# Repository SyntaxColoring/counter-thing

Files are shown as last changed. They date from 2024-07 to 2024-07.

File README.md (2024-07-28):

# Introduction

The Counter Thing is a hardware device with a button and numeric display. It currently counts days going up, and resets to 0 when you press the button.

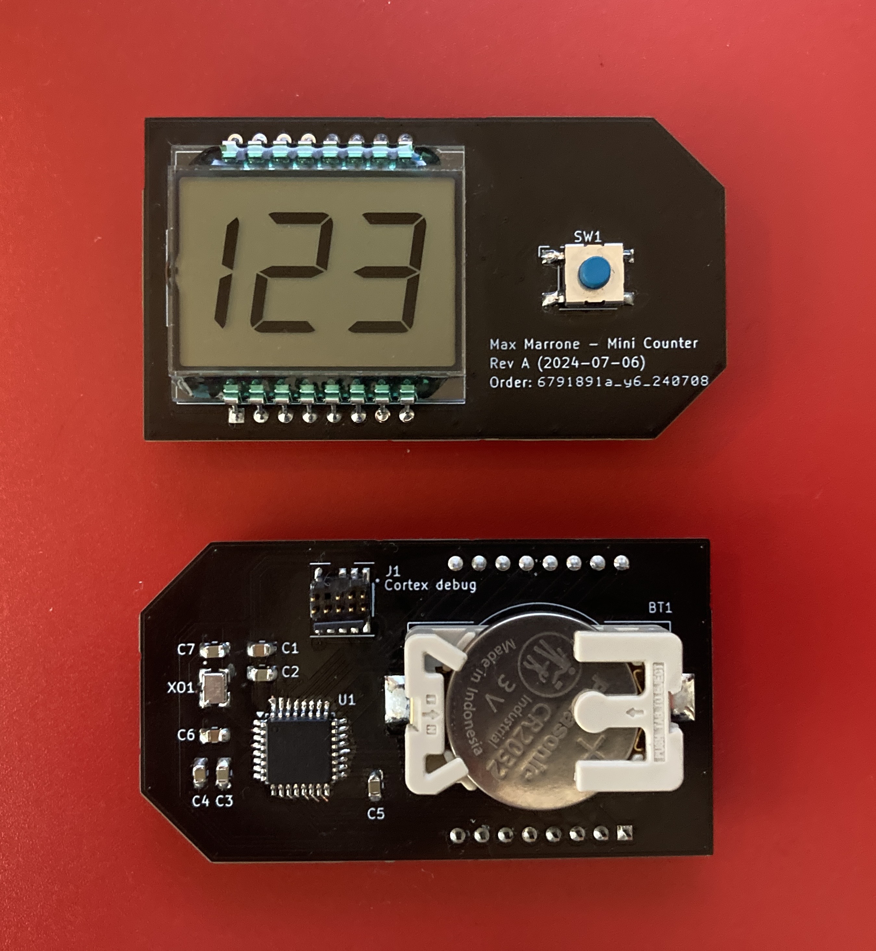
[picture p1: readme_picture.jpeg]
The front and back of the printed circuit board assembly. The front has a numeric display and a button. The back has a CR2032 battery and several smaller components. PCB front and back


I should run ~1 year on a CR2032 battery and keep time with a drift of <15 minutes/year.

I use a few as household reminders, like keeping track of how many days it's been since I've last vacuumed or watered my plants.

This repository holds everything for the project (electronics and software).

# File organization

[pcb/](./pcb/) has the KiCad project files for the latest version of the board. [pcb/fabrication_outputs/](./pcb/fabrication_outputs) has pre-exported Gerbers and such, ready to send to a fab. I used JLCPCB, but any of them will probably work.

[firmware/](./firmware/) has the STM32CubeIDE project files and source code for the firmware.

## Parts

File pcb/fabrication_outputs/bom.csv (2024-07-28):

Designator | Footprint | Quantity | Value | LCSC Part #
BT1 | BA2032SM | 1 | BA2032SM | BA2032SM
C1 | 0805 | 1 | 10u | C0805C106K8PAC7800
C2, C3, C5, C7 | 0805 | 4 | 100n | C0805C104K5RAC7210
C4 | 0805 | 1 | 1u | C0805C105K4RAC7800
C6 | 0805 | 1 | 10n | C0805C103K1RAC7800
DS1 | LCD-A2X1C50TR | 1 | LCD-A2X1C50TR | LCD-A2X1C50TR
J1 | SAMTEC_FTSH-105-X-X-DV-007-P-X | 1 | FTSH-105-01-L-DV-007-K | FTSH-105-01-L-DV-007-K
SW1 | SW_SPST_Omron_B3FS-101xP | 1 | B3FS-1015 | B3FS-1015
U1 | LQFP-32_7x7mm_P0.8mm | 1 | STM32L010K4T6 | STM32L010K4T6
XO1 | OSC_ECS-327KE-TR_HandSolder | 1 | ECS-327KE-TR | ECS-327KE-TR

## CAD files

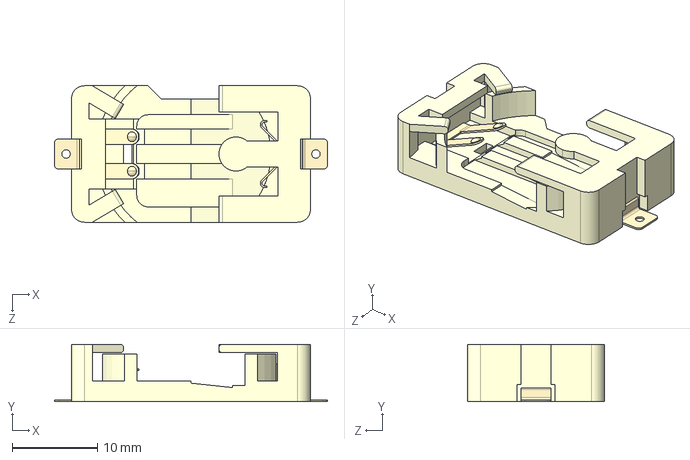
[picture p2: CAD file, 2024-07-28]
pcb/project_libraries/3d/BA2032SM.step
32.0 x 6.70 x 16.0 mm

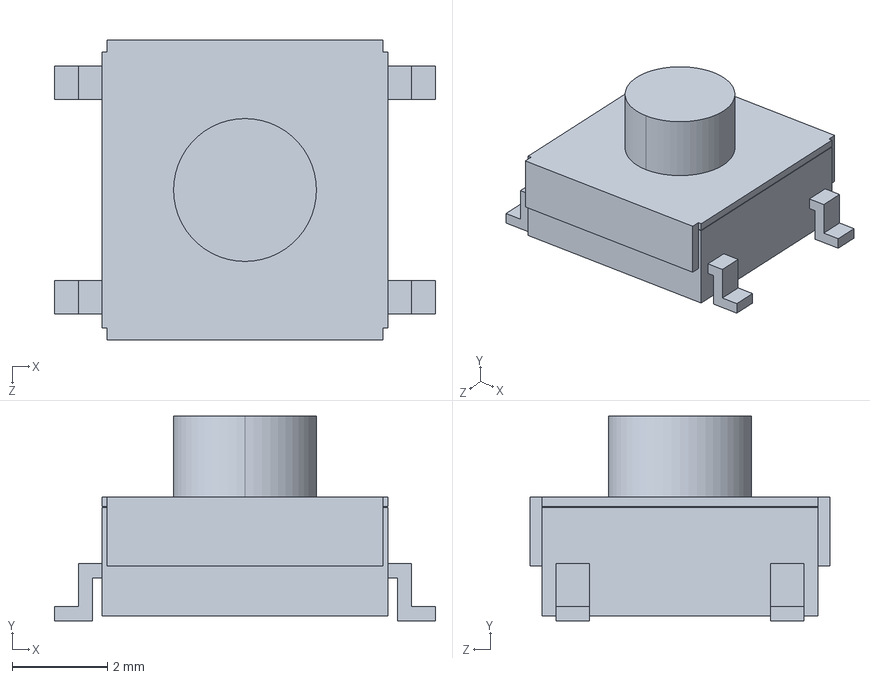
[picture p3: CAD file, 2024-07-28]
pcb/project_libraries/3d/B3FS_101[].step
8.00 x 4.30 x 6.30 mm

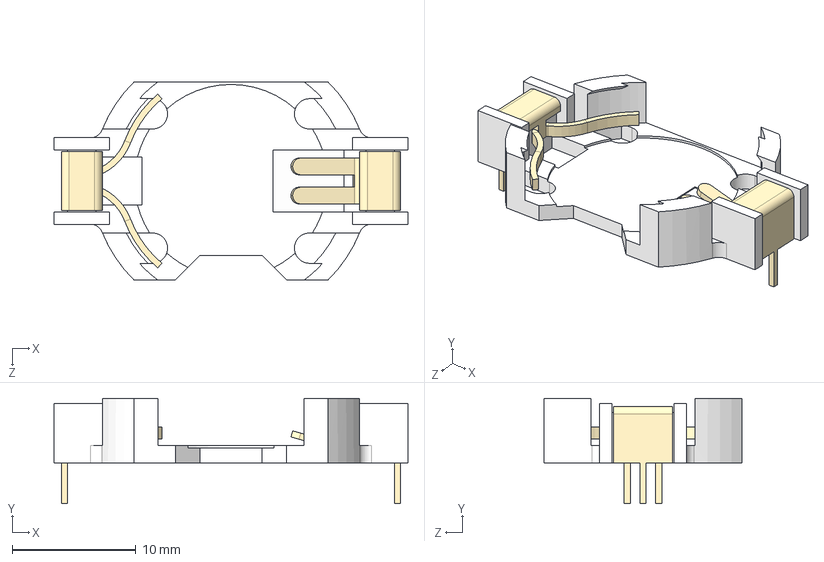
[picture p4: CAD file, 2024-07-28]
pcb/project_libraries/3d/BU2032-1-G.STEP
28.6 x 8.50 x 16.0 mm

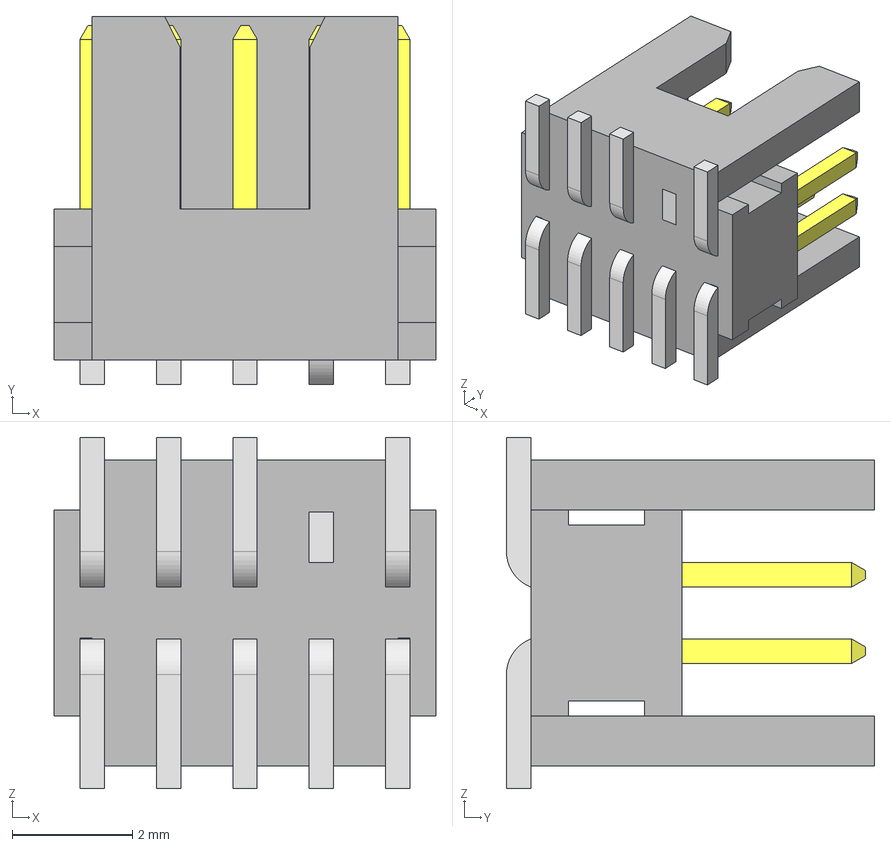
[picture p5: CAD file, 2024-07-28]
pcb/project_libraries/3d/FTSH-105-X-X-DV-007-P-X.step
6.35 x 6.12 x 5.84 mm
FTSH-105-01-L-DV-007-K_body
FTSH-105-01-L-DV-007-K_pins1
FTSH-105-01-L-DV-007-K_pins2

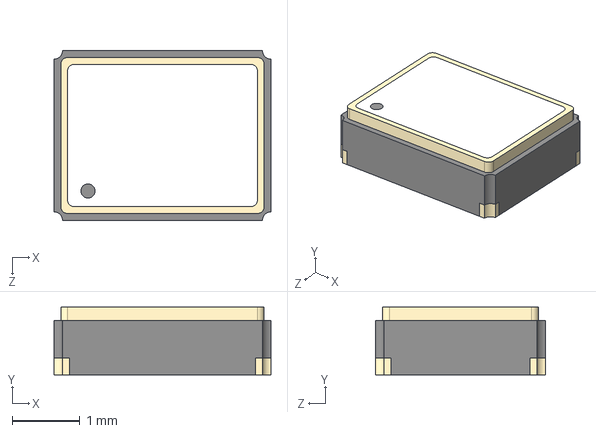
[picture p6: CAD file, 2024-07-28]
pcb/project_libraries/3d/ECS-327KE-TR.step
3.20 x 1.00 x 2.50 mm

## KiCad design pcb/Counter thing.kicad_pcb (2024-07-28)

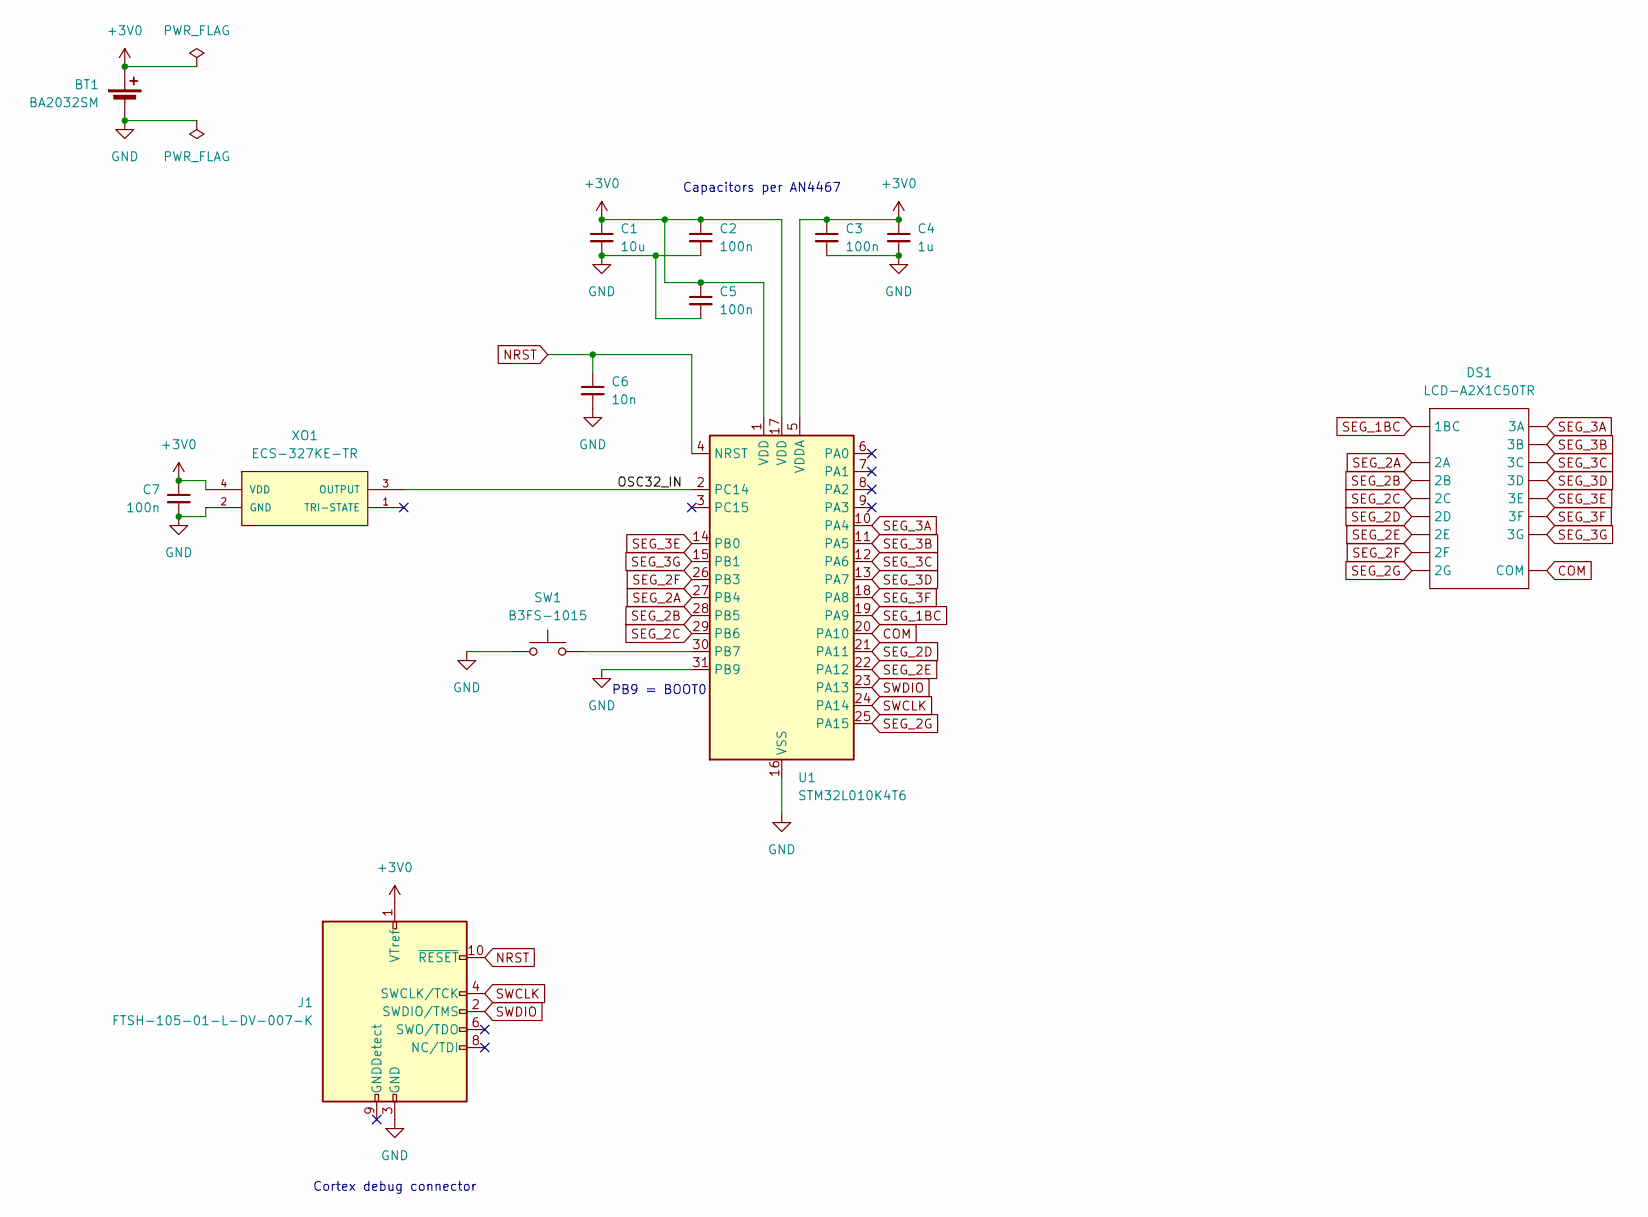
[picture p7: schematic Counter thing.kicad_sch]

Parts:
BT1: BA2032SM; MPN BA2032SM
C1: 10u; C_0805_2012Metric_Pad1.18x1.45mm_HandSolder; MPN C0805C106K8PAC7800
C2, C3, C5, C7: 100n; C_0805_2012Metric_Pad1.18x1.45mm_HandSolder; MPN C0805C104K5RAC7210
C4: 1u; C_0805_2012Metric_Pad1.18x1.45mm_HandSolder; MPN C0805C105K4RAC7800
C6: 10n; C_0805_2012Metric_Pad1.18x1.45mm_HandSolder; MPN C0805C103K1RAC7800
DS1: LCD-A2X1C50TR; MPN LCD-A2X1C50TR
J1: FTSH-105-01-L-DV-007-K; SAMTEC_FTSH-105-X-X-DV-007-P-X; MPN FTSH-105-01-L-DV-007-K
SW1: B3FS-1015; SW_SPST_Omron_B3FS-101xP; MPN B3FS-1015
U1: STM32L010K4T6; LQFP-32_7x7mm_P0.8mm; MPN STM32L010K4T6
XO1: ECS-327KE-TR; OSC_ECS-327KE-TR_HandSolder; MPN ECS-327KE-TR

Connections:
+3V0: BT1.1 (+), C1.1, C2.1, C3.1, C4.1, C5.1, C7.1, J1.1 (VTref), U1.1 (VDD), U1.5 (VDDA), U1.17 (VDD), XO1.4 (VDD)
/OSC32_IN: U1.2 (PC14), XO1.3 (OUTPUT)
COM: DS1.16 (COM), U1.20 (PA10)
GND: BT1.2 (-), C1.2, C2.2, C3.2, C4.2, C5.2, C6.2, C7.2, J1.3 (GND), J1.5 (GND), SW1.2, U1.16 (VSS), U1.31 (PB9), U1.32 (VSS), XO1.2 (GND)
NRST: C6.1, J1.10 (~RESET), U1.4 (NRST)
unnamed: SW1.1, U1.30 (PB7)
SEG_1BC: DS1.1 (1BC), U1.19 (PA9)
SEG_2A: DS1.11 (2A), U1.27 (PB4)
SEG_2B: DS1.10 (2B), U1.28 (PB5)
SEG_2C: DS1.9 (2C), U1.29 (PB6)
SEG_2D: DS1.15 (2D), U1.21 (PA11)
SEG_2E: DS1.14 (2E), U1.22 (PA12)
SEG_2F: DS1.12 (2F), U1.26 (PB3)
SEG_2G: DS1.13 (2G), U1.25 (PA15)
SEG_3A: DS1.8 (3A), U1.10 (PA4)
SEG_3B: DS1.7 (3B), U1.11 (PA5)
SEG_3C: DS1.6 (3C), U1.12 (PA6)
SEG_3D: DS1.5 (3D), U1.13 (PA7)
SEG_3E: DS1.4 (3E), U1.14 (PB0)
SEG_3F: DS1.2 (3F), U1.18 (PA8)
SEG_3G: DS1.3 (3G), U1.15 (PB1)
SWCLK: J1.4 (SWCLK/TCK), U1.24 (PA14)
SWDIO: J1.2 (SWDIO/TMS), U1.23 (PA13)

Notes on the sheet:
PB9 = BOOT0
Capacitors per AN4467
Cortex debug connector

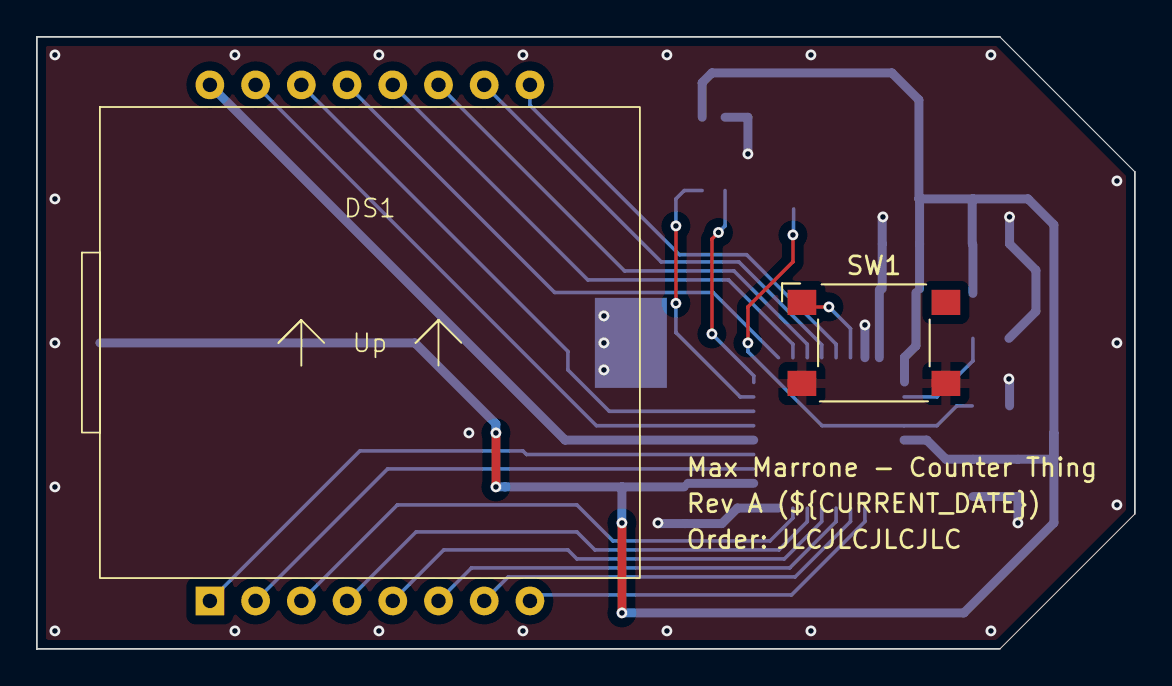
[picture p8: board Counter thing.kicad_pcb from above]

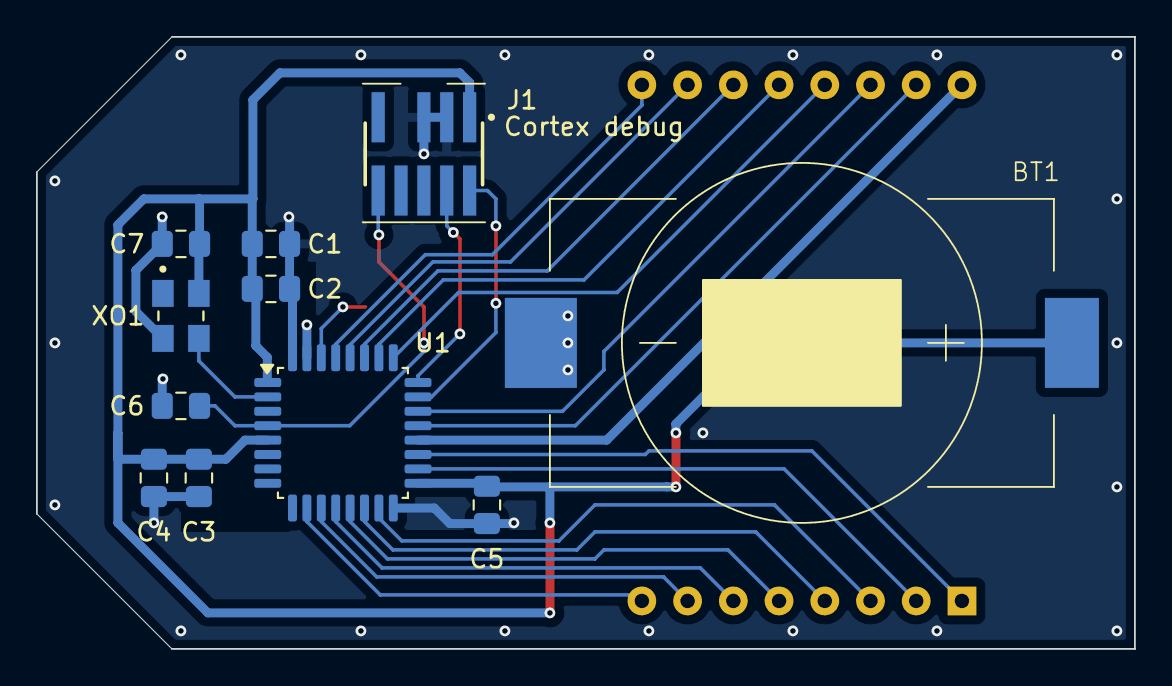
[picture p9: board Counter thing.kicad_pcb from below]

Board: 2 copper layers, 61.0 x 34.0 mm, 13 parts (11 on the bottom side), 23 nets.

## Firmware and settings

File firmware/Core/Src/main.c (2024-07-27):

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
/* Includes ------------------------------------------------------------------*/
#include "main.h"

/* USER CODE BEGIN Includes */
#include <stdatomic.h>
#include <stdint.h>

#include "display.h"
/* USER CODE END Includes */

RTC_HandleTypeDef hrtc;

/* USER CODE BEGIN PV */
const static unsigned TICKS_PER_SECOND = 32;
const static unsigned TICKS_PER_PERIOD = TICKS_PER_SECOND * 60 * 60 * 24; // Days.
//const static unsigned TICKS_PER_PERIOD = TICKS_PER_SECOND / 2; // Half-seconds, for testing.
const static unsigned MAXIMUM_COUNT = 199;

// Cleared when there is a button press to acknowledge. Set when it's been acknowledged.
volatile static atomic_flag button_flag = ATOMIC_FLAG_INIT;
/* USER CODE END PV */

void SystemClock_Config(void);
static void MX_GPIO_Init(void);
static void MX_RTC_Init(void);
/* USER CODE BEGIN 0 */

void HAL_GPIO_EXTI_Callback(uint16_t GPIO_Pin)
{
	atomic_flag_clear(&button_flag);
}

/* USER CODE END 0 */

/**
  * @brief  The application entry point.
  * @retval int
  */
int main(void)
{

  /* USER CODE BEGIN 1 */
  atomic_flag_test_and_set(&button_flag);
  /* USER CODE END 1 */

  /* MCU Configuration--------------------------------------------------------*/

  /* Reset of all peripherals, Initializes the Flash interface and the Systick. */
  HAL_Init();

  /* Configure the system clock */
  SystemClock_Config();

  /* Initialize all configured peripherals */
  MX_GPIO_Init();
  MX_RTC_Init();
  /* USER CODE BEGIN 2 */
  _Bool phase = 0;

  // As a uint64_t, we could have 1 tick per nanosecond and this could still count hundreds of years.
  uint64_t ticks_since_last_clear = 0;
  /* USER CODE END 2 */

  /* Infinite loop */
  /* USER CODE BEGIN WHILE */
  while (1)
  {
	  const _Bool button_pressed_since_last_loop = !atomic_flag_test_and_set(&button_flag);
	  if (button_pressed_since_last_loop)
	  {
		  ticks_since_last_clear = 0;
	  }

	  const unsigned current_count = ticks_since_last_clear / TICKS_PER_PERIOD % (MAXIMUM_COUNT + 1);

	  write_display_pins(encode_number(current_count), phase);

	  ticks_since_last_clear++;
	  phase = !phase;

	  __HAL_PWR_CLEAR_FLAG(PWR_FLAG_WU);
	  HAL_PWR_EnterSTOPMode(PWR_LOWPOWERREGULATOR_ON, PWR_STOPENTRY_WFI);

    /* USER CODE END WHILE */

    /* USER CODE BEGIN 3 */
  }
  /* USER CODE END 3 */
}

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


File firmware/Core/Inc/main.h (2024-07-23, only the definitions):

#define SEG_3A_Pin GPIO_PIN_4
#define SEG_3A_GPIO_Port GPIOA
#define SEG_3B_Pin GPIO_PIN_5
#define SEG_3B_GPIO_Port GPIOA
#define SEG_3C_Pin GPIO_PIN_6
#define SEG_3C_GPIO_Port GPIOA
#define SEG_3D_Pin GPIO_PIN_7
#define SEG_3D_GPIO_Port GPIOA
#define SEG_3E_Pin GPIO_PIN_0
#define SEG_3E_GPIO_Port GPIOB
#define SEG_3G_Pin GPIO_PIN_1
#define SEG_3G_GPIO_Port GPIOB
#define SEG_3F_Pin GPIO_PIN_8
#define SEG_3F_GPIO_Port GPIOA
#define SEG_1BC_Pin GPIO_PIN_9
#define SEG_1BC_GPIO_Port GPIOA
#define COM_Pin GPIO_PIN_10
#define COM_GPIO_Port GPIOA
#define SEG_2D_Pin GPIO_PIN_11
#define SEG_2D_GPIO_Port GPIOA
#define SEG_2E_Pin GPIO_PIN_12
#define SEG_2E_GPIO_Port GPIOA
#define SEG_2G_Pin GPIO_PIN_15
#define SEG_2G_GPIO_Port GPIOA
#define SEG_2F_Pin GPIO_PIN_3
#define SEG_2F_GPIO_Port GPIOB
#define SEG_2A_Pin GPIO_PIN_4
#define SEG_2A_GPIO_Port GPIOB
#define SEG_2B_Pin GPIO_PIN_5
#define SEG_2B_GPIO_Port GPIOB
#define SEG_2C_Pin GPIO_PIN_6
#define SEG_2C_GPIO_Port GPIOB
#define BUTTON_Pin GPIO_PIN_7
#define BUTTON_GPIO_Port GPIOB
#define BUTTON_EXTI_IRQn EXTI4_15_IRQn

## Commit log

2024-07-23 Use STOP mode and RTC auto-wakeup.
    This brings current consumption down from ~380 uA to ~33 uA.
2024-07-23 Use low-power regulator in stop mode.
    This brings us down to ~18 uA.
2024-07-23 Clear count on button press.
2024-07-23 Fix modular arithmetic error.
    [main.c]
2024-07-28 Add PCB files.
    [B3FS_101[].step, BA2032SM.step, BU2032-1-G.STEP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]
2024-07-28 Ignore more KiCad files.
2024-07-28 Update KiCad page titles.
    [Counter thing.kicad_pcb, Counter thing.kicad_sch]
2024-07-28 Add KiCad fabrication outputs.
    [bom.csv, designators.csv, positions.csv]
2024-07-29 Remove KiCad project local settings from Git.

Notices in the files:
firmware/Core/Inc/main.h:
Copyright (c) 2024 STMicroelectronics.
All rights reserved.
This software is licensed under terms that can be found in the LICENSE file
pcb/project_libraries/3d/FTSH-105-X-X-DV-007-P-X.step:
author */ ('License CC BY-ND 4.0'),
